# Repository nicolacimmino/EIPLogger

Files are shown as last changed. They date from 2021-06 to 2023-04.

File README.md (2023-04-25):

# IAQLogger

An Indoor Air Quality monitor I built for a client who wanted to display the capabilities of their filters in a fair exposition cabinet.

The device sports an ESP32, a SPS30 particulate matter sensor, an iAQ-Core CO2 and TVOC sensor, and an eInk Display for coolness.

One of the requirements was also to expose both live and histyorical data through an API to drive a WEB frontend (not part of this project).

All code has been released under the GNU General Public License V3, with permission of the client, as it doesn't represent their core business and allowed me to showcase my projects. 

## Hardware

The assembled contraption, with a generous dose of hot glue to add extra sturdiness during trasportation (I know, I know, it's not production ready). At the bottom you can barely see the large (2500 mAh) battery that ensures at least a full day at the fair with WiFi and all sensors enabled.

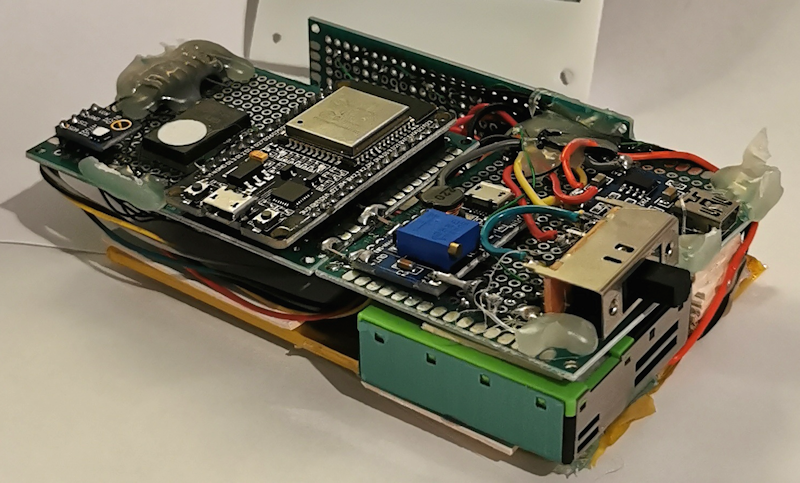
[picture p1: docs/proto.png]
proto


The temporary nature of the hand-wiring and hot glueing is hidden in a 3D-Printed enclosure.

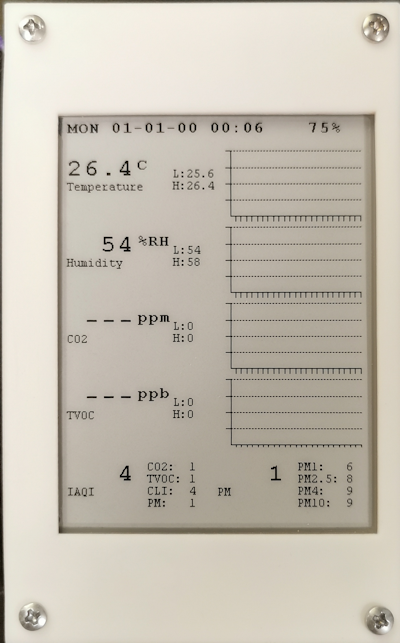
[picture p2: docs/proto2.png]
assembled proto


## API

The `/info` endpoint returns current live data from the device.

````
GET 'http://iaqm.local/info'

{
    "ip": "192.168.8.134",
    "disk": {
        "used": "411389",
        "total": "1378241"
    },
    "battery": {
        "level": "73",
        "voltage": "3.88"
    },
    "iaq": {
        "temperature": "26.0",
        "humidity": "58",
        "co2": "-9999",
        "tvoc": "-9999",
        "pm1": "7",
        "pm2p5": "9",
        "pm4": "10",
        "pm10": "10"
    }
}
````

The `/logs/{n-days}` endpoint allows to fetch a CSV data log {n-days} in the past

````
GET 'http://192.168.8.134/log/0'

TIME,T,H,CO2,TVOC,PM1,PM2.5,PM4,PM10
2022-03-15T00:00,22.4,35,3620,998,2,2,2,3,4118
2022-03-15T00:01,22.5,37,3675,1013,4,5,5,5,4132
2022-03-15T00:02,22.7,36,3690,1018,4,5,5,5,4138
...
````

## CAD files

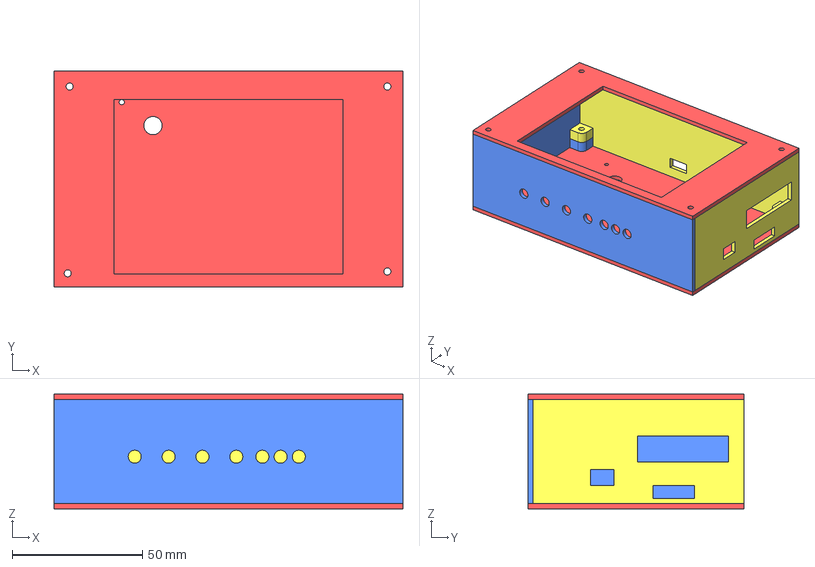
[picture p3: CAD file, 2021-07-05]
box/EIPLoggerBox.FCStd
134.0 x 83.0 x 44.0 mm
Frame_BR
Frame_TL
Cover B
Cover T

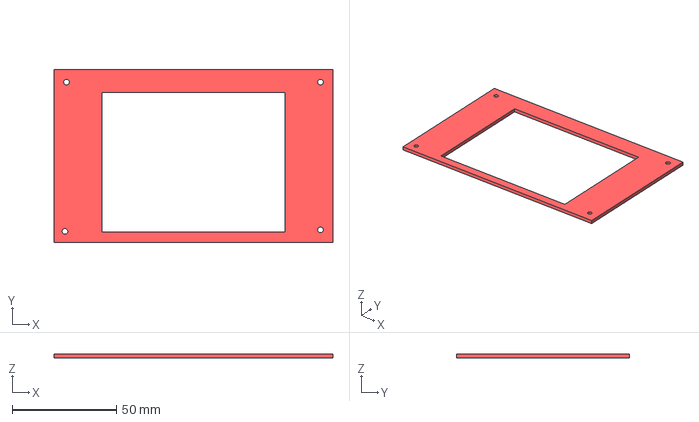
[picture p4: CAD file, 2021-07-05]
box/CoverT.step
134.0 x 83.0 x 2.00 mm

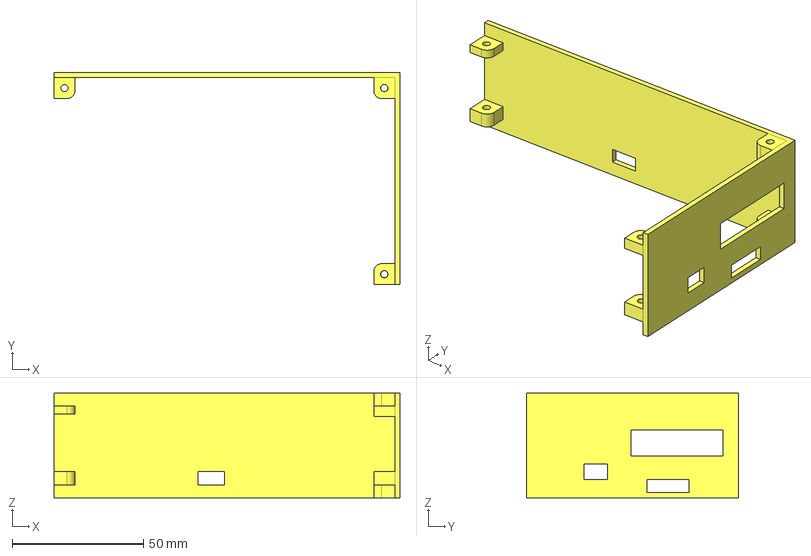
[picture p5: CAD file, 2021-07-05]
box/FrameBR.step
132.0 x 81.0 x 40.0 mm

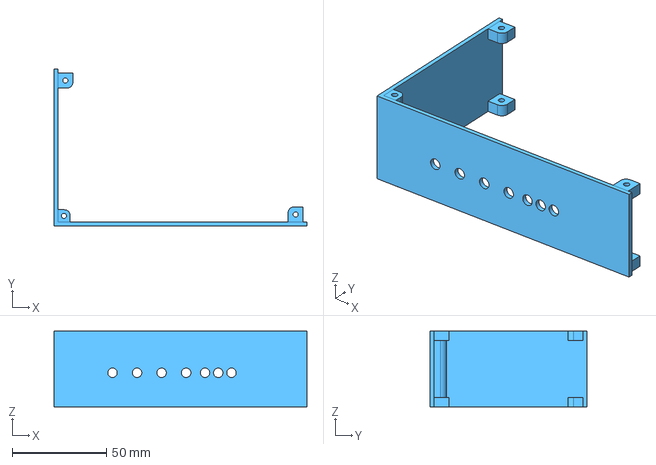
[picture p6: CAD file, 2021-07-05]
box/FrameTL.step
134.0 x 83.0 x 40.0 mm

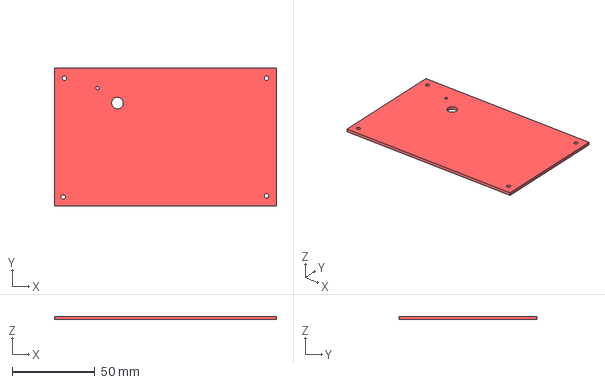
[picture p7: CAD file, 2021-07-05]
box/CoverB.step
134.0 x 83.0 x 2.00 mm

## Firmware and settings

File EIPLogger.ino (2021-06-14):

#include <Arduino.h>
#include <Wire.h>

#include "src/Button.h"
#include "src/Peripherals.h"
#include "src/ModeManager.h"

void onButtonPress()
{
    PowerManager::onUserInteratcion();

    ModeManager::currentDisplay->loop();
}

void onButtonAClick()
{
    DIAGNOSTIC("BTN,A");
    
    ModeManager::changeMode();
    onButtonPress();
}

void onButtonBClick()
{
    DIAGNOSTIC("BTN,B");

    ModeManager::currentDisplay->onBClick();
    onButtonPress();
}

void onButtonCClick()
{
    DIAGNOSTIC("BTN,C");

    onButtonPress();
}

void onButtonALongPress()
{
    DIAGNOSTIC("BTN,AL");

    // ModeManager::currentDisplay->powerDown();
    // PowerManager::enterL3();
}

void setup()
{
    DIAGNOSTIC("SETUP")

    if (esp_sleep_get_wakeup_cause() != ESP_SLEEP_WAKEUP_TIMER)
    {
        delay(500);

        Serial.begin(115200);

        Peripherals::setup();        
        ModeManager::setup();
        Status::setup();

        Peripherals::buttonA->registerOnClickCallback(onButtonAClick);
        Peripherals::buttonA->registerOnLongPressCallback(onButtonALongPress);
        Peripherals::buttonB->registerOnClickCallback(onButtonBClick);
        Peripherals::buttonC->registerOnClickCallback(onButtonCClick);
    }

    //Peripherals::rtc->set(0, 52, 12, 6, 15, 5, 21);
}

void loop()
{
    PowerManager::loop();
    Peripherals::loop();
    ModeManager::currentDisplay->loop();

    Status::loop();

    PowerManager::enterL1();

    //PowerManager::enterL2();
}

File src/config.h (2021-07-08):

#ifndef __TEMPERATURE_LOGGER_CONFIG_H__
#define __TEMPERATURE_LOGGER_CONFIG_H__

#define DIAGNOSTIC_ENABLE

#ifdef DIAGNOSTIC_ENABLE
#define DIAGNOSTIC(S)                      \
    Serial.printf("%d,%s\n", millis(), S); \
    delay(100);
#else
#define DIAGNOSTIC(S) // do nothing
#endif

#define SHT2x_ADDR 0x40
#define IAQ_ADDR 0x5A
#define RTC_ADDR 0x68

#define PIN_BUTTON_A GPIO_NUM_2
#define PIN_BUTTON_B GPIO_NUM_4
#define PIN_BUTTON_C GPIO_NUM_33
#define PIN_BUTTON_D GPIO_NUM_32

#define PIN_BUTTON_A_SEL GPIO_SEL_2
#define PIN_BUTTON_B_SEL GPIO_SEL_4
#define PIN_BUTTON_C_SEL GPIO_SEL_33
#define PIN_BUTTON_D_SEL GPIO_SEL_32

#define PIN_LED_RED 5
#define PIN_LED_YELLOW 21 
#define PIN_LED_BLUE 22

#define PWM_CHANNEL_RED_LED 0
#define PWM_CHANNEL_BLUE_LED 1

#define PIN_SWITCH_SENSE 23

#define PIN_SCL 18
#define PIN_SDA 19

#define PIN_VBAT_SENSE 34

#define DISPLAY_MODES 2

#define LIGHTNING_INT 0x08
#define DISTURBER_INT 0x04
#define NOISE_INT 0x01

#define SMALL_STATUS_SCREEN_FONT &Font8
#define BIG_POWER_DOWN_SCREEN_FONT &Font24

#define MAIN_DISPLAY_MID_FONT &Font16
#define MAIN_DISPLAY_LARGE_FONT &Font24
#define MAIN_DISPLAY_LABEL_FONT &Font12
#define MAIN_DISPLAY_SMALL_FONT &Font12

#define STATUS_DISPLAY_MID_FONT &Font16

#define BOOT_DISPLAY_MID_FONT &Font16

#define TEXT_BUFFER_SIZE 512

#define NO_VALUE -9999

#define MAX_POLLEN_COUNTS 16

#define PIN_INT 13

#define POWER_SAVE_TIMEOUT_MS 20000

#define MAX_LOG_FILES 15

#endif

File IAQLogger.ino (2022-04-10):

#include <Arduino.h>
#include <Wire.h>

#include <FS.h>
#include <SPIFFS.h>

#include "src/Button.h"
#include "src/Peripherals.h"
#include "src/ModeManager.h"
#include "src/ApiServer.h"

ApiServer *apiServer = NULL;

void onButtonPress()
{
    PowerManager::onUserInteratcion();
}

void onButtonAClick()
{
    DIAGNOSTIC("BTN,A");

    onButtonPress();

    ModeManager::changeMode();
}

void onButtonBClick()
{
    DIAGNOSTIC("BTN,B");

    onButtonPress();
}

void onButtonCClick()
{
    DIAGNOSTIC("BTN,C");

    onButtonPress();
}

void onButtonDClick()
{
    DIAGNOSTIC("BTN,D");

    onButtonPress();
}

void onButtonALongPress()
{
    DIAGNOSTIC("BTN,AL");

    // ModeManager::currentDisplay->powerDown();
    // PowerManager::enterL3();
}

void setup()
{
    DIAGNOSTIC("SETUP")

    if (esp_sleep_get_wakeup_cause() != ESP_SLEEP_WAKEUP_TIMER)
    {
        delay(500);

        Serial.begin(115200);

        DataLog::instance()->setup();
        Peripherals::setup();
        Peripherals::loop();
        ModeManager::setup();

        Peripherals::buttonA->registerOnClickCallback(onButtonAClick);
        Peripherals::buttonA->registerOnLongPressCallback(onButtonALongPress);
        Peripherals::buttonB->registerOnClickCallback(onButtonBClick);
        Peripherals::buttonC->registerOnClickCallback(onButtonCClick);
        Peripherals::buttonD->registerOnClickCallback(onButtonDClick);

        PowerManager::enterL1();

        DataLog::instance()->showContent();
    }

    //Peripherals::rtc->set(0, 38, 18, 2, 13, 7, 21);
}

unsigned long lastAppLoopTime = 0;

void appLoop()
{
    PowerManager::loop();
    Peripherals::loop();

    if (lastAppLoopTime == 0 || millis() - lastAppLoopTime > 60000)
    {
        lastAppLoopTime = millis();

        ModeManager::currentDisplay->loop();
        DataLog::instance()->loop();
    }
}

void loop()
{
    if (Status::serverMode)
    {
        appLoop();

        if (!apiServer)
        {
            PowerManager::enterL0();
            apiServer = new ApiServer();
        }

        apiServer->loop();

        return;
    }

    PowerManager::enterL1();

    appLoop();

    PowerManager::enterL2();
}

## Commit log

2021-05-15 First working time display, mostly a copy of TemperatureLogger adapted for the new HW
2021-05-16 Add power up/down
2021-05-16 Custom SHT21 driver, fed up with the library issues on ESP
    [Peripherals.cpp, SHT2x.cpp]
2021-05-16 Refactor SHT21 driver
2021-05-18 Cleanup power modes
2021-05-18 Add pressure sensor
2021-05-19 Fix intermittent IAQ reading issues
    [Peripherals.cpp]
2021-05-24 Scan for expected devices only
2021-05-29 Fix powerdown, better IAQI levels
2021-05-31 More stable reconnects
    [EIPLoggerBox.FCStd]
2021-06-05 Fix first redraw has no data
    [EIPLogger.ino]
2021-06-05 Wire up thunrstorm detector interrupt, temporarily lose wake on B
2021-06-05 Temproray solution for button B
2021-06-05 Better button B handling
2021-06-20 Fix wrong PM reading
    [DataLog.cpp, Peripherals.cpp]
2021-06-21 Add battery monitor
2021-06-21 Log battery
2021-06-25 Add buttons and LEDs
2021-06-25 Wake up on button press
2021-06-26 Balance LEDs brightnesses
2021-06-26 Show battery percentage
2021-06-30 Finalise box
    [EIPLoggerBox.FCStd]
2021-07-01 Box tweaks
    [EIPLoggerBox.FCStd]
